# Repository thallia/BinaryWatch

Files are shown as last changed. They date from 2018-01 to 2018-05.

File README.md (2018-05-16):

# BinaryWatch
My first project designing and creating *everything*. 

Current board rev: *4.1*

Supplies I went through for breadboard testing:
  * atmega328p-pu
  * sn74hc595n x2
  * LEDs x10 
  * 16MHz external crystal
  * 32.768kHz external crystal
  * 2 22pF capacitors
  * 2 0.1uF capacitors
  * two buttons for configuring time
  * one button for sleep/wakeup
  * jumper wires
  
  * arduino uno (for easier programming in the beginning)
  
Supplies for PCB:
  * (SMD) atmega328p-au 
  * 74hc595 SMD shift registers x2
  * JST right angle connector
  * 400mAh Li-Po battery
  * LEDs 1206 SMD x10 (or flat top, whatever you prefer.)
  * 32.768kHz SC-32S SMD crystal
  * SMD capacitors 0805 22pF x2
  * SMD capacitors 0805 12.5pF x2
  * 3 buttons
  * 10k SMD resistors 0805 x1
  * 2k SMD resistors 0805 x10 (in testing for LED brightness)
  * PCB (oshpark)
  * 3D printed case (fusion360)

**PCB designed on:** eagleCAD

**3D case designed on:** fusion360

**CURRENT TASK:** This project is complete!

Blog Posts following development:

**Basis:**  https://thalliatree.wordpress.com/2017/12/25/74hc595-texas-instruments-shift-registers/

**Intro:**  https://thalliatree.wordpress.com/2018/01/01/project-hype-binary-wristwatch/

**Breadboard Hardware (with Uno):**   https://thalliatree.wordpress.com/2018/01/26/atmega328p-microcontroller-74hc595-shift-register-setup-and-test-binary-watch/

**Code - Part 1:**  https://thalliatree.wordpress.com/2018/01/29/code-part-1-binary-watch/

**Code - Part 2:**  https://thalliatree.wordpress.com/2018/01/31/code-part-2-binary-watch/

**Breadboard Hardware (without Uno):**    https://www.thalliatree.net/posts/prepping-the-atmega-hardware-test-bw.html

**Mock Up PCB with coin cells + early schematic:**   https://thalliatree.wordpress.com/2018/02/05/mock-up-pcb-binary-watch/

**Code - Part 3:**   https://thalliatree.wordpress.com/2018/03/16/code-part-3-binary-watch/

**Atmega328p 32.768kHz, sleep modes, and new schematic:**   https://thalliatree.wordpress.com/2018/03/26/atmega328p-32-768khz-sleep-modes-and-new-schematic-binary-watch/

**Final Code, Schematic, and PCB layout:**   https://thalliatree.wordpress.com/2018/04/03/final-code-schematic-and-pcb-binary-watch/

**PCB 95% Complete:**   https://thalliatree.wordpress.com/2018/05/03/pcb-95-complete-binary-watch/

**Binary Watch | Complete:**  https://thalliatree.wordpress.com/2018/05/14/binary-watch-complete

For later revisions: 
-  Power: The charging and power circuit needs to be on the board itself. That way I can charge it and not have to worry about buying a bunch of LiPo batteries over and over.
- Experimenting with new power: I want to try powering this thing from a coin cell again. I have 2 other boards with this design, so I'm going to solder them together, but with different resistor types on the LEDs to see how much current the LEDs and microcontroller are drawing. That way I can estimate what the best resistor value is for brightness + mAh value of battery to get.
- The 3D case is cool with the PCB exposed, but it ain't cool because it's exposed to the weather and other wet and sticky things. Therefore I must cover it up. The lid for case I design next will likely be screwed on, 1) for easier access and 2) for better security of the PCB. Depending on how secure I want it, I may add some kind of sealant. We'll see...
- 3D case: If I add a charging port, it'll need a hole for the plug.
- Through-hole LEDs: if the PCB is to be covered by the case, SMD LEDs aren't going to shine through very well. I have some cool cylindrical blue LEDs that should work, so I'll have to design the case cover to sit around/on top of them, which requires a new PCB design entirely.
- With the PCB case covering the top, I'll need to either add holes for the pushbuttons or design a way to put them on the sides of the case.
- Watch strap: I'm planning on weaving some leather cord in a celtic knot fashion, or maybe some cool braided thing. I've been looking at some chunkier weaves on Pinterest, but I haven't found the right one yet.
- With the new case top, I may make it thicker and engrave some cool circuit-looking designs around the LEDs poking through and paint the engravings an electric blue color. Electric blue is a great idea.

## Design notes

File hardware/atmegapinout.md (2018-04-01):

# ATMega328P Pinout
## Connecting what pins from the ATMega to the shift registers?

ATMEGA **to** 74HC595

Digital Pin 0 (PCINT16/RXD) PD0 **to** OE (output enable) pin 13

Digital Pin 1 (PCINT17/TXD) PD1 **to** ST_CP (clock pin) pin 12

Digital Pin 2 ((PCINT18/INT0) PD2) **to** inDisplay

Digital Pin 3 (PCINT19/OC2B/INT1) PD3 **to** 

Digital Pin 4 (PCINT20/XCK/T0) PD4 **to** SH_CP (latch pin) pin 11

Digital Pin 5 (PCINT21/OC0B/T1) PD5 **to** DS (serial data) pin 14

Digital Pin 6 ((PCINT22/OC0A/AIN0) PD6) **to** inHour

Digital Pin 7 ((PCINT23/AIN1) PD7) **to** inMinute

# Shift Register I/O to LED

### Hours

- Pin Q1 = 1
- Pin Q2 = 2
- Pin Q3 = 4
- Pin Q4 = 8

### Minutes

- Pin Q5 = 1
- Pin Q6 = 2
- Pin Q7 = 4
- (second shift register)
- Pin Q0 = 8
- Pin Q1 = 16
- Pin Q2 = 32

# GND and Vcc

- AREF to Vcc
- AVcc to Vcc
- GND to GND
- Vcc to 10kOhm resistor to RESET
- Master Reclear to Vcc
- Two 0.1uF capacitors connecting GND and Vcc on both sides (Vcc/GND and AVcc/GND)

# External Clock

- Two GNDed 22pF capacitors to 16MHz crystal to XTAL1 and XTAL2 (if not using sleep modes)

OR

- Two GNDed 22pF caps to 32.768kHz crystal to XTAL1 and XTAL2 (if using sleep modes & burned fuse bytes)

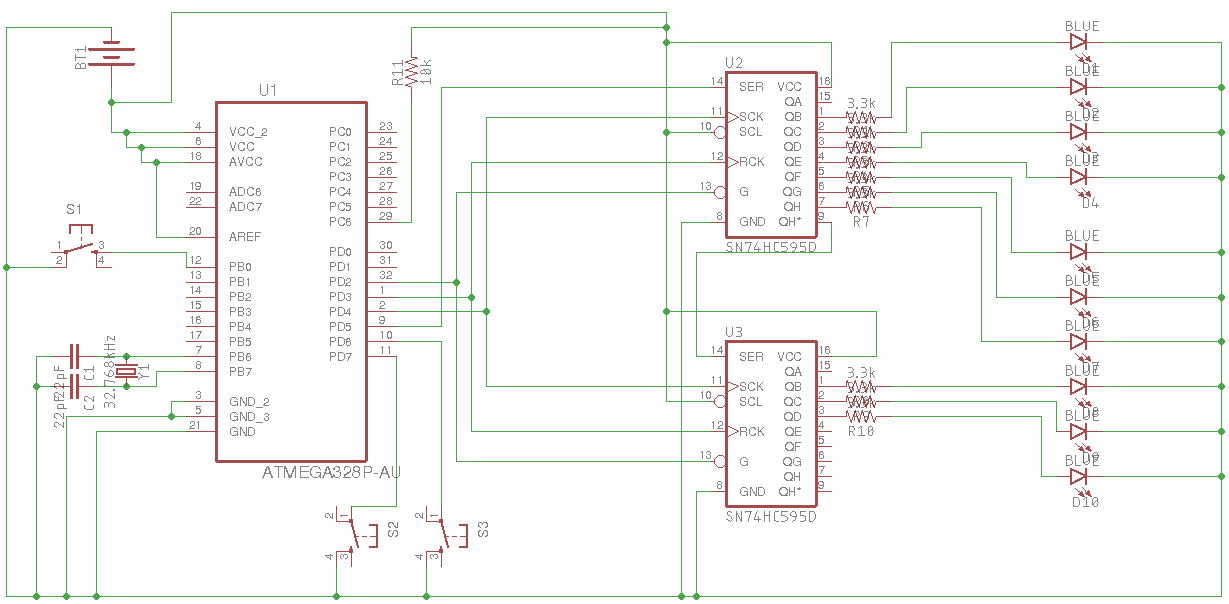
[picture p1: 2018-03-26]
hardware/schematics/binarywatchrev4.png

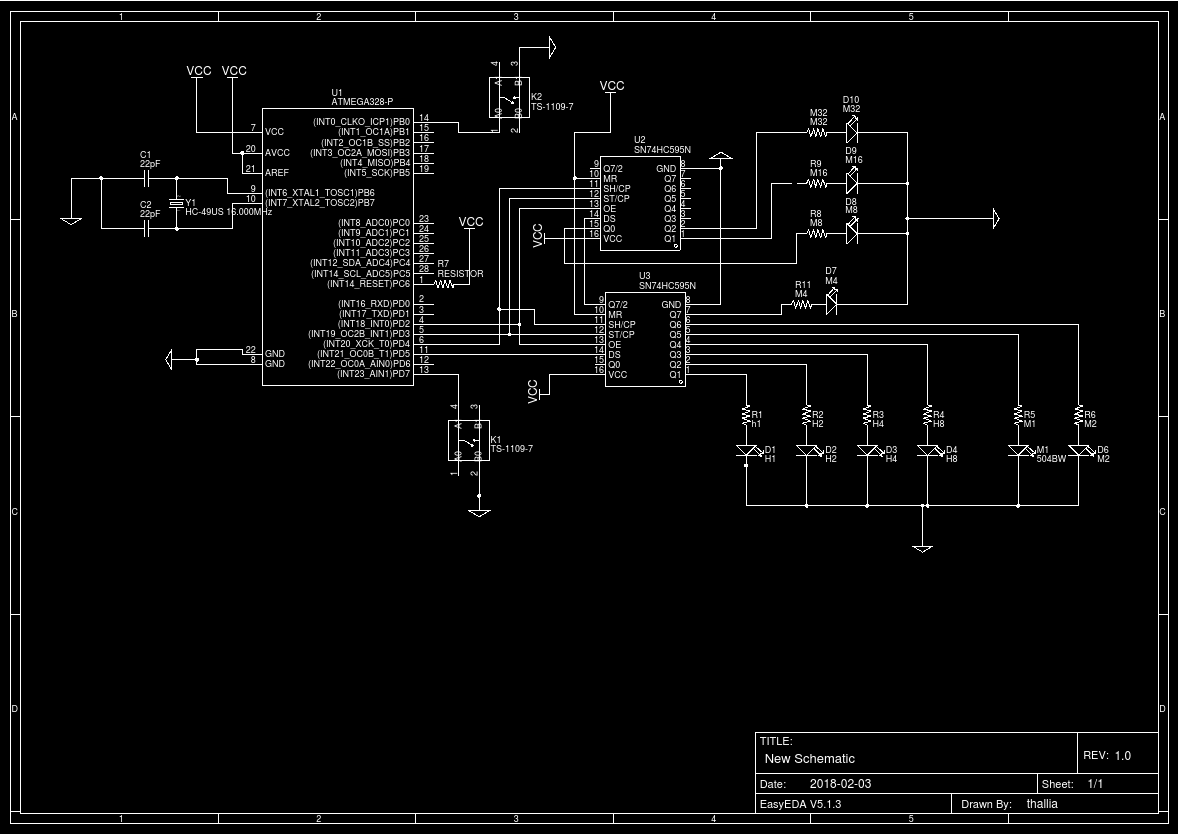
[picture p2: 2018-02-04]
hardware/schematics/schematicrv1.png

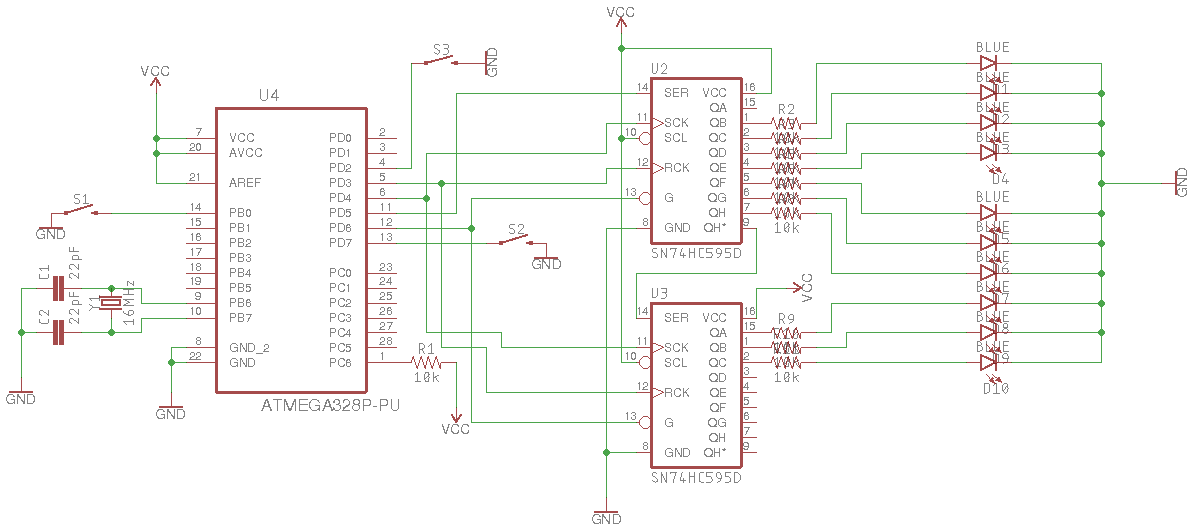
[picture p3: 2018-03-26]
hardware/schematics/binarywatchrev3-1.png

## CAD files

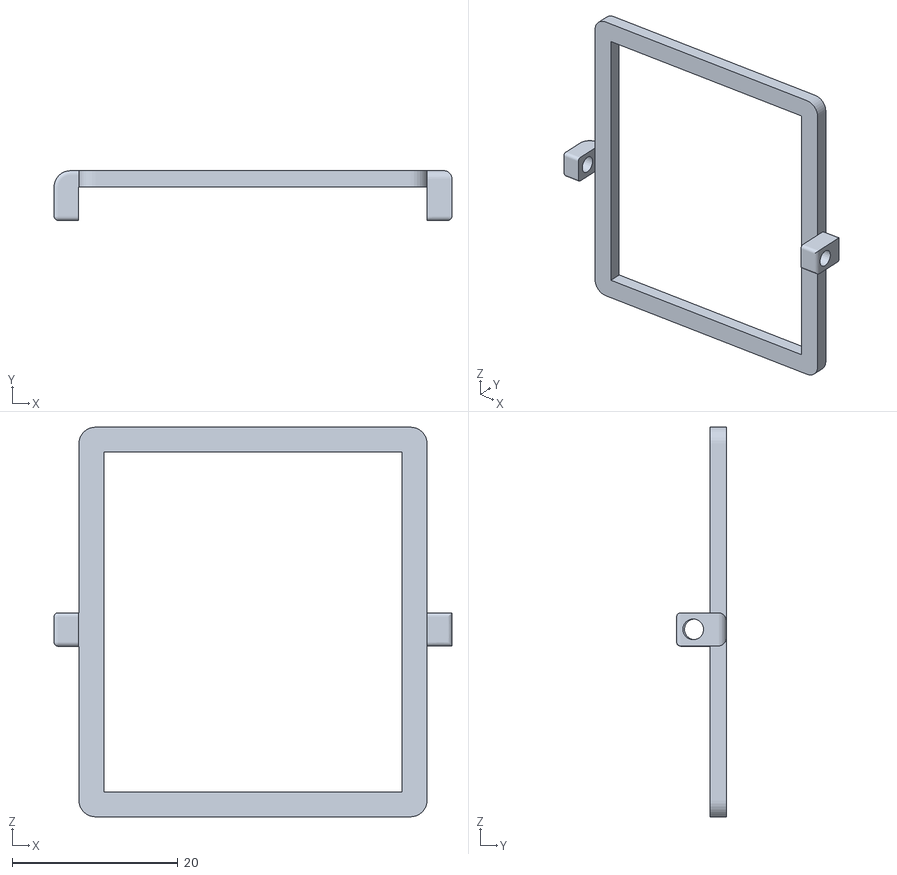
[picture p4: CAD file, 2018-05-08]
hardware/3d-case-rev-2/lid.stl
48.0 x 6.00 x 47.0

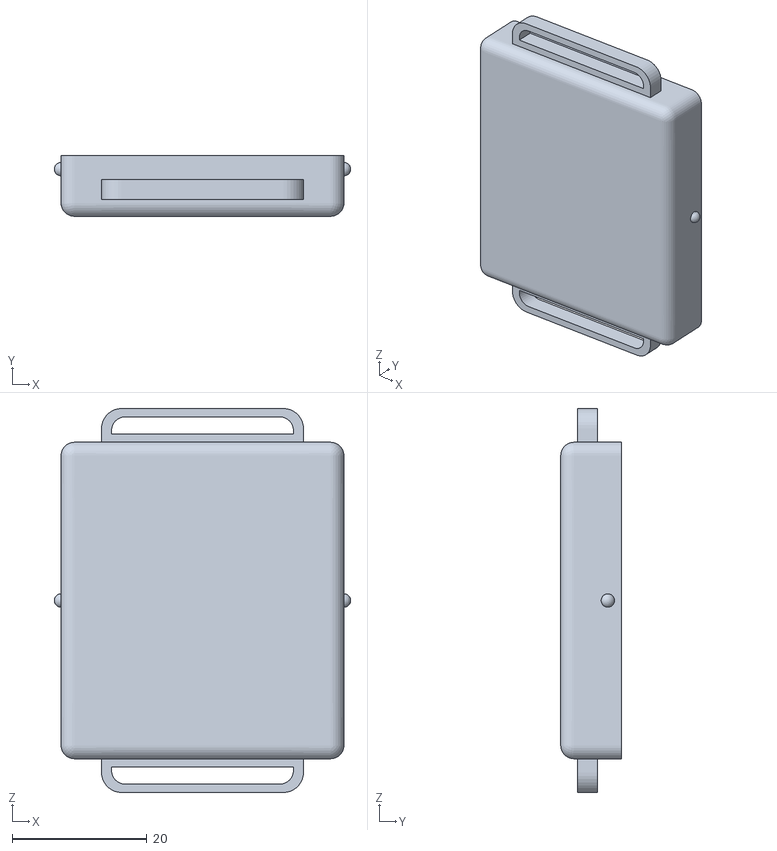
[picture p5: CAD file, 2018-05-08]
hardware/3d-case-rev-2/case.stl
44.0 x 9.00 x 57.0

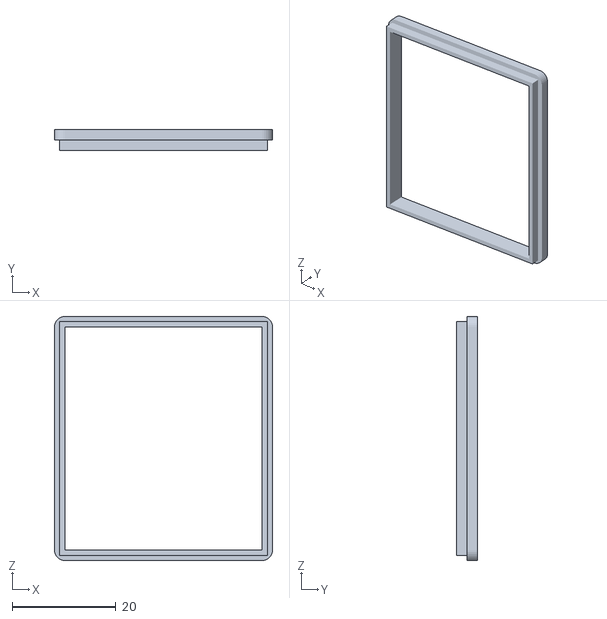
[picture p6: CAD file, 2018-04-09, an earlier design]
hardware/3d-case-rev-1/lid.stl
42.0 x 4.00 x 47.0

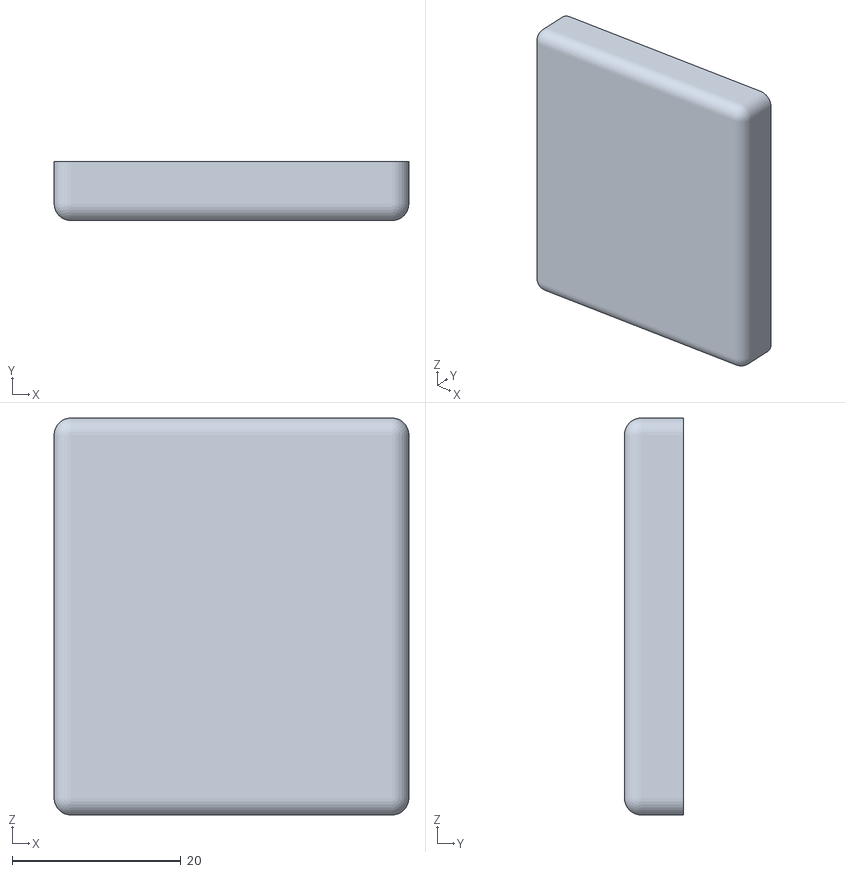
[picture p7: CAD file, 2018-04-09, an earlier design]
hardware/3d-case-rev-1/base.stl
42.0 x 7.00 x 47.0

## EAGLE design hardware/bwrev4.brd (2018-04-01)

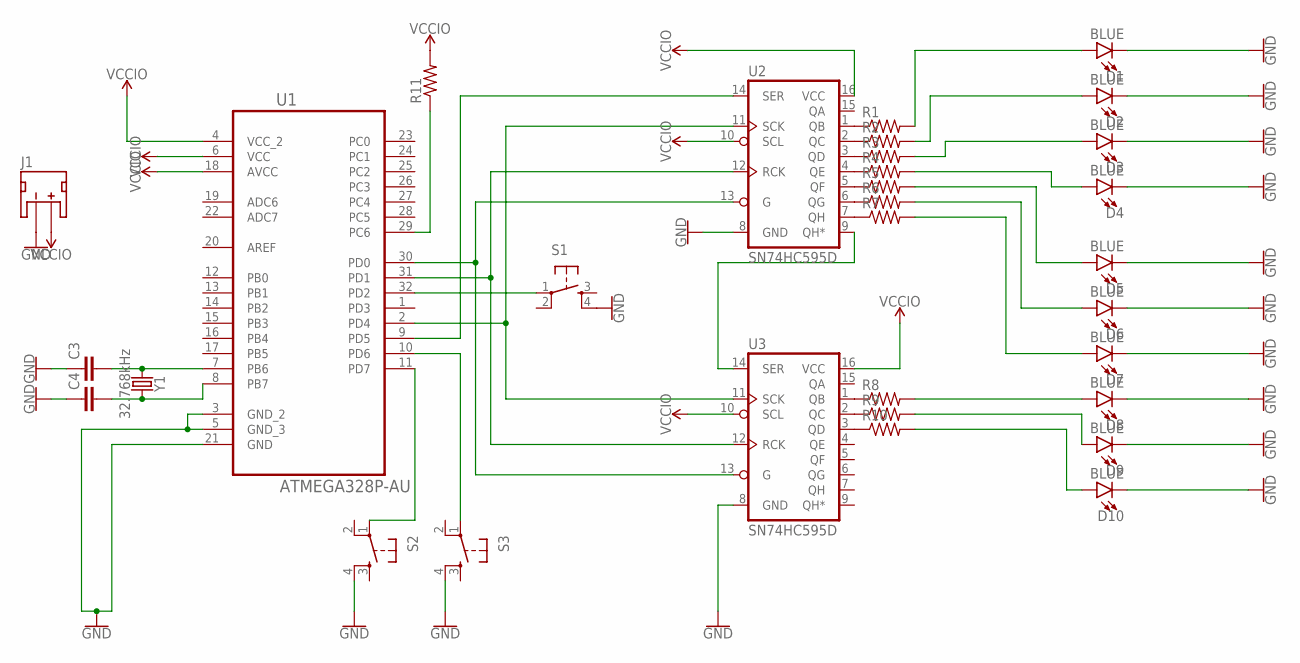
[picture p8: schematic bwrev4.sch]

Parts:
C3, C4: C-EUC0805; C0805
D1, D2, D3, D4, D5, D6, D7, D8, D9, D10: BLUE; LED-1206
J1: JST_2MM_MALE; JST-2-SMD
R1, R2, R3, R4, R5, R6, R7, R8, R9, R10, R11: R-US_M0805; M0805
S1, S2, S3: TAC_SWITCHPTH; TACTILE-PTH
U1: ATMEGA328P-AU; QFP80P900X900X120-32N
U2, U3: SN74HC595D; SO16
Y1: 32.768kHz; CRYSTAL-SMD-3.2X1.5MM

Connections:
GND: C3.1, C4.1, D1.C, D2.C, D3.C, D4.C, D5.C, D6.C, D7.C, D8.C, D9.C, D10.C, J1.1 (-), S1.4, S2.4, S3.4, U1.3 (GND_2), U1.5 (GND_3), U1.21 (GND), U2.8 (GND), U3.8 (GND)
unnamed: S1.1, U1.32 (PD2)
unnamed: R1.1, U2.1 (QB)
unnamed: R2.1, U2.2 (QC)
unnamed: R3.1, U2.3 (QD)
unnamed: R4.1, U2.4 (QE)
unnamed: R5.1, U2.5 (QF)
unnamed: R6.1, U2.6 (QG)
unnamed: R7.1, U2.7 (QH)
unnamed: R8.1, U3.1 (QB)
unnamed: R9.1, U3.2 (QC)
unnamed: S3.1, U1.10 (PD6)
unnamed: C4.2, U1.8 (PB7), Y1.P$2 (2)
unnamed: C3.2, U1.7 (PB6), Y1.P$1 (1)
unnamed: R10.1, U3.3 (QD)
unnamed: D4.A, R4.2
unnamed: D5.A, R5.2
unnamed: D1.A, R1.2
unnamed: D2.A, R2.2
unnamed: D3.A, R3.2
unnamed: D6.A, R6.2
unnamed: D7.A, R7.2
unnamed: D8.A, R8.2
unnamed: D9.A, R9.2
unnamed: D10.A, R10.2
unnamed: U2.9 (QH*), U3.14 (SER)
unnamed: U1.30 (PD0), U2.13 (G), U3.13 (G)
unnamed: U1.9 (PD5), U2.14 (SER)
unnamed: U1.31 (PD1), U2.12 (RCK), U3.12 (RCK)
unnamed: U1.2 (PD4), U2.11 (SCK), U3.11 (SCK)
unnamed: R11.1, U1.29 (PC6)
unnamed: S2.1, U1.11 (PD7)
VCCIO: J1.2 (+), R11.2, U1.4 (VCC_2), U1.6 (VCC), U1.18 (AVCC), U2.10 (SCL), U2.16 (VCC), U3.10 (SCL), U3.16 (VCC)

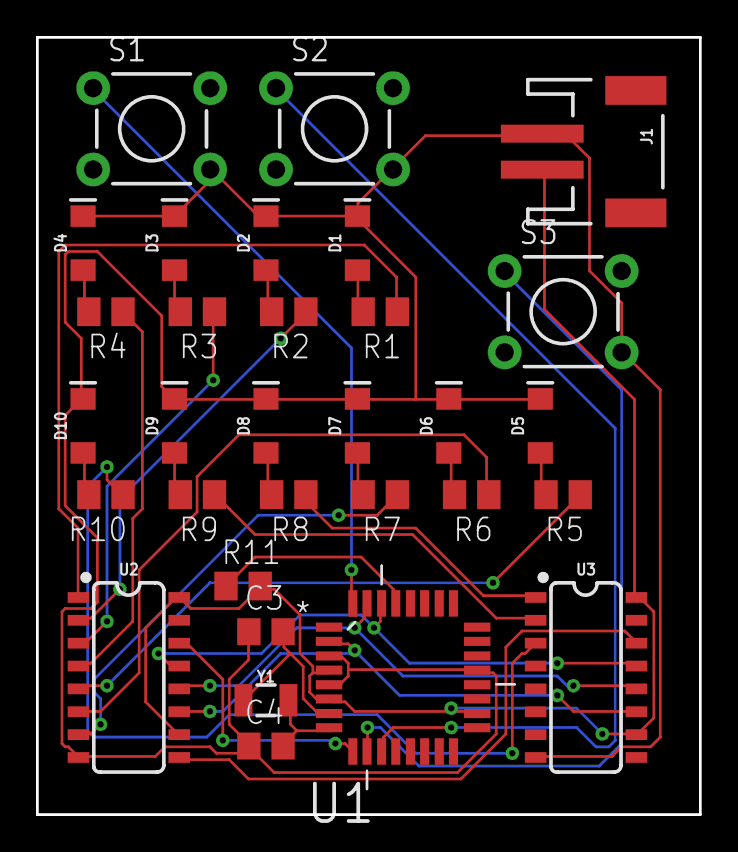
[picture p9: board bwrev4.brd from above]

Board: 2 copper layers, 36.8 x 43.2 mm, 31 parts (0 on the bottom side), 33 nets.

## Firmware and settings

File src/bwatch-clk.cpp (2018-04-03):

/*
*
* written by: thallia
* date: 3-14-18
* last edit: 3-31-18
* Specifically only using the 32kHz clock, adjusting the hardware to fit it.
*
*/
#include <avr/sleep.h>
#include <avr/power.h>

const int inDisplay = 2;  // display button
const int inHour = 6;     // hour button
const int inMinute = 7;   // minute button

const int outputEN = 0;   // enable chip signal
const int clockP = 1;     // clock signal pin
const int latchP = 4;     // latch signal pin
const int dataP = 5;      // data write pin

// Default date/time settings whenever program starts
int seconD = 0;
int minutE = 0;
int houR = 1;
int halfDay = 1;

int checkDisplay = 0;

// interrupt on Timer 2 compare "A" completion - does nothing
EMPTY_INTERRUPT (TIMER2_COMPA_vect);

// Boolean --> Void / pin signal
// If true, enableOutput writes an ON signal to the OE gate, allowing LED output
// if false, enableOutput writes OFF signal to the OE gate.
void enableOutput(boolean state){
  if(state){
    digitalWrite(outputEN, LOW); // OE is NOTed, which is why we write LOW to
                                 // trigger a HIGH signal.
  } else{
    digitalWrite(outputEN, HIGH);
  }
}

void latchTick(){
  digitalWrite(latchP, HIGH);
  digitalWrite(latchP, LOW);
  digitalWrite(clockP, HIGH); // turns the clock on
  digitalWrite(clockP, LOW); // turns clock off
}

// Integer --> Void / Pin Signal
// writeData writes the new data to the dataPin.
void writeData(){
  digitalWrite(dataP, HIGH);
  latchTick();
  digitalWrite(dataP, LOW);
}

// No input --> No output
// checkHour checks if the hourButton has been pressed. If true, increase
// the LED output.
void checkHour(){
  int hourButton = digitalRead(inHour);
  if(hourButton == LOW){
    houR++;
    seconD = 0;
  }
}

// no input --> no output
// check minute checks if the minButton has been pressed. If true, increase
// the min LED output.
void checkMin(){
  int minButton = digitalRead(inMinute);
  if(minButton == LOW){
    minutE++;
    seconD = 0;
  }
}

// Integer --> LED signal (hours)
// writes to the hour display
void hourDisplay(int houR){
  if(houR >= 1){
    for (int x = 3; x >= 0; x--){
      int bit = bitRead(houR, x);
        if(bit == 1){
          writeData();
        } else {
          latchTick();
       }
    }
  }
}

// integer --> LED signal (minutes)
// writes to the minute display
void minDisplay(int minutE){
  for(int x = 5; x >= 0; x--){
    int bit = bitRead(minutE, x);
    if(bit == 1){
      writeData();
    } else {
      latchTick();
    }
  }
}

// integer --> void
// AmPm makes sure that we see regular time, not military time.
void ampm(int state){
  if(state >= 1){
    writeData();
  } else {
    latchTick();
  }
}

/* ------------------------------------------------------------------------- */

void setup()
 {

   pinMode(clockP, OUTPUT);
   pinMode(outputEN, OUTPUT);
   pinMode(latchP, OUTPUT);
   pinMode(dataP, OUTPUT);

   pinMode(inHour, INPUT_PULLUP);
   pinMode(inMinute, INPUT_PULLUP);
   pinMode(inDisplay, INPUT_PULLUP);

  // clock input to timer 2 from XTAL1/XTAL2
  ASSR = bit (AS2);

  // set up timer 2 to count up to 32 * 1024  (32768)
  // timer counts to 32*1024 which takes 1 sec, then triggers interrupt
  TCCR2A = bit (WGM21);                             // CTC
  TCCR2B = bit (CS20) | bit (CS21) | bit (CS22);    // Prescaler of 1024
  OCR2A =  31;              // count to 32 (zero-relative)

  // enable timer interrupts
  TIMSK2 |= bit (OCIE2A);

  // disable ADC
  ADCSRA = 0;

  // turn off everything we can
  power_adc_disable();
  power_spi_disable();
  power_twi_disable();
  power_timer0_disable();
  power_timer1_disable();
  power_usart0_disable();

  // full power-down doesn't respond to Timer 2
  set_sleep_mode(SLEEP_MODE_PWR_SAVE);

  // get ready ...
  sleep_enable();

  }  // end of setup

void loop()
  {
  enableOutput(false);

  // turn off brown-out enable in software
  MCUCR = bit(BODS) | bit(BODSE);
  MCUCR = bit(BODS);

  // sleep, finally!
  sleep_cpu();

  // we awoke! pulse the clock hand
  // digitalWrite(tick, ! digitalRead(tick));
  seconD++;
  // one minute every 60sec
  if(seconD >= 59){
    minutE++;
    seconD = 0;
  }

  // one hour every 60min
  if(minutE >= 59){
    houR++;
    minutE = 0;
  }

  // halfDay every 12hrs
  if(houR >= 13){
    halfDay++;
    houR = 1;
    minutE = 1;
  }

  // reset AM/PM
  if(halfDay >= 2){
    halfDay = 0;
    houR = 1;
    minutE = 0;
  }

  checkHour();
  checkMin();

  checkDisplay = digitalRead(inDisplay);
  if (checkDisplay == LOW){
    ampm(halfDay);
    minDisplay(minutE);
    hourDisplay(houR);
    latchTick();
    enableOutput(true);
  }
}  // end of loop: loop back, sleep, wake up after 1 second

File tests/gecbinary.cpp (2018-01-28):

/*
 * AUTHOR: Gector (with lovely comments from thallia)
 * Written: 12/21/2017
 * Last Edit: 1-27-18 - thallia's descriptive comment
 */

// -------------------------------------- \\
// ------------ VARIABLES --------------- \\
// -------------------------------------- \\

// Our time units.
int second=0, minute1=1, minute2=1, hour=1, halfDay=1;

// Physical pin numbers. 
const int inHourPin = 12, inMinutePin = 13;
const int outEnable = 2;
const int clockPin = 3;
const int dataPin = 5;
const int latchPin = 4;

const int clearAmount = 16; // If you add more shift registers to clear.

int wait = 0; // Add delay to the clock to see it shift stuff


// -------------------------------------- \\
// ------------ FUNCTIONS --------------- \\
// -------------------------------------- \\

// Shift bits down by one (positive edge triggered)

///////// THALLIA COMMENT //////////
/* clockReg takes looks like it makes a new variable "hold", then places the int value of 'wait' inside of it.
with digitalWrite, it outputs the clockpin HIGH, sending a signal to the clock pin of the shift register.
the delay....does something.

Delay waits for whatever the value of "hold" is.
digitalWrite then writes the clockpin LOW, and waits 1 second. This seems to be used as a way to clock the shift registers. */
///////////////////////////////////////////////////////
void clockReg(int hold = wait){
  digitalWrite(clockPin, HIGH);
  delay(hold);
  digitalWrite(clockPin, LOW);
  delay(hold);
}

// Grab a new bit from input (positive edge triggered)

////////// THALLIA COMMENT //////////
/* I'm guessing latch does the same thing as clockReg, but on the latch pin to get the new value. we don't have to specify *how* to get the value, only tell the pin to latch it. We like smart pins. */
/////////////////////////////////////////////////
void latch(int hold = wait){
  digitalWrite(latchPin, HIGH);
  delay(hold);
  digitalWrite(latchPin, LOW);
  delay(hold);
}

// Activate a single bit

//////////// THALLIA COMMENT ///////////////
/* alright, this is a little different.
 activateBit takes....an integer variable named hold with the value of wait inside of it?

digitalWrite writes the dataPin, which activates the LED, I think.
latch(hold) takes hold as an argument and latches the data.

activateBit grabs writes the old data, grabs the new data, and then writes the pin low, we aren't ready to latch the new stuff yet. */
///////////////////////////////////////////////////
void activateBit(int hold = wait){
  digitalWrite(dataPin, HIGH);
  latch(hold);
  clockReg(hold);
  digitalWrite(dataPin, LOW);
}

// set whether or not the LEDs are lit or not. (if this isn't done they flicker with the calculations)

///////// THALLIA COMMENT ///////////
/* enableOutput takes a boolean state as an argument.
 if the boolean state is true,if OE will be written LOW. But because that pin is inverted input, it'll be high. Otherwise, if false, OE will be written high, and turned off. */
////////////////////////////////////////////////////
void enableOutput(boolean state){
  if(state) {
    digitalWrite(outEnable, LOW);
  } else {
    digitalWrite(outEnable, HIGH);
  }
}

//... clear all.
//////// THALLIA COMMENT ////////////////
/* clearAll doesn't take any arguments afaik.
 It writes the dataPin low/off and loops:

*if x is 0, x less than the value of clearAmount, x++? then execute clockReg and latch with values 0.

clockReg will take 0 as an arg, running the clock and latching the new data. This resets everything to new values, I guess? */
/////////////////////////////////////////////////
void clearAll(){
  digitalWrite(dataPin, LOW);
  for(int x = 0;x <= clearAmount; x++){
    clockReg(0);
    latch(0);
  }
}

// Display hours
//////////////////THALLIA COMMENT/////////////////////
/* displayHour is obvs for displaying the actual time on the LEDs.

 if hour is greater than or equal to 1:
         for x equal to 3, greater than zero, read in the value from bitRead, which reads the number from "hour" and the bit in the x's place.

if the local variable "bit" is equal to 1, then write data HIGH, latch a new value, and shift it down, then turn data off.
otherwise, keep ticking. */
//////////////////////////////////////////////////////
void displayHour(int hour){
  if(hour >= 1) {
    for(int x = 3; x >= 0; x--) {
      int bit = bitRead(hour, x);
      if(bit == 1){ // Clock and data
        digitalWrite(dataPin, HIGH);
        latch();
        clockReg();
        digitalWrite(dataPin, LOW);
      } else { // Just clock
        latch();
        clockReg();
      }
    }
  }
}

// Sends on extra bit if it's PM, sends one extra clock if it's AM

////////////// THALLIA COMMENT ////////////////
/* AmPm returns nothing. It takes a state with an integer datatype. If state is greater than one, write data, latch new data, shift the clock. Otherwise, keep ticking. */
///////////////////////////////////////////////
void AmPm(int state){
  if(state >= 1) {
    digitalWrite(dataPin, HIGH);
    latch();
    clockReg();
    digitalWrite(dataPin, LOW);
  } else {
    latch();
    clockReg();
  }
}

// Set the first line of LEDs designated to minutes

///////////// THALLIA COMMENT ////////////////
/* this sets the first set of LEDs as the tens row.

 if the bit read from the local variable 'tens' is equal to 1, write, latch, and clock

otherwise, keep ticking */
//////////////////////////////////////////////
void displayMinL1(int tens){
  for(int x = 3; x >= 0; x--) {
    int bit = bitRead(tens, x);
    if(bit == 1){ // Clock and data
      digitalWrite(dataPin, HIGH);
      latch();
      clockReg();
      digitalWrite(dataPin, LOW);
    } else { // Just clock
      latch();
      clockReg();
    }
  }
}

// Set the second line of LEDs designated to minutes
void displayMinL2(int ones){
    for(int x = 3; x >= 0; x--) {
      int bit = bitRead(ones, x);
      if(bit == 1){ // Clock and data
        digitalWrite(dataPin, HIGH);
        latch();
        clockReg();
        digitalWrite(dataPin, LOW);
      } else { // Just clock
        latch();
        clockReg();
      }
    }
}

// Set all bits in sequence - usefuly for both lookinng cool and for debugging.

/////////////THALLIA COMMENT /////////////////
/* view takes an integer or hold as arg.
 if the given arg is equal to 0, less than clearAmount, it'll activate a bit -- I think whatever hold is, which is the pin number?? */
//////////////////////////////////////////////
void view(int hold = wait){
  for(int x = 0;x <= clearAmount; x++){
    activateBit(hold);
  }
}

// -------------------------------------- \\
// -------------- MAIN ------------------ \\
// -------------------------------------- \\
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

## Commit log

2018-01-03 added eagleCAD gerber and board files for rev2.1
    [bwv2.1.brd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]
2018-01-28 added initial binary watch rev 1 code
    It's in good standing, it works, albeit slightly better than how Gector's reacted on my atmega. I altered the minute function, but it's
    still acting up, so that will be the next thing to fix.
    [bwv2.1.brd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]
2018-01-29 fixed the minute portion of the code
    replaced the if(millis() - lastTick) with the correct stuff, turns out that had been goofing the whole thing up. Now onto deep sleep.
2018-01-30 solved why minutes won't go to 59 had to add else's to the IF functions for the buttons. Now to find out why they aren't receiving input, and why having both checkHour and checkMin causes some sort o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
2018-01-31 modified the inHour and inMinute to be input and activated the pullup resistors
2018-01-31 fixed the pullup resistor code, it works with the arduino uno!
2018-01-31 updated README to most recent additions, current task, and list of blog post documentation of process
2018-01-31 added the correct pinout of ATMega --> shift register, and shift register I/O to LED number
2018-02-04 added rest of pins to connect to to make circuit work
2018-02-04 added rest of pins to connect to to make circuit work - oops forgot caps
2018-02-04 schematic from EasyEDA for scholarship; going to redo in eagleCAD. Document.
2018-03-13 cleaned up the bclock and replaced with bwatch. Bwatch is where i'm gonna test all the disabled modules.
    [bwatch2-0.cpp]
2018-03-16 updated task, PCB supplies, cleaned up code.
2018-03-25 figured out the sleep modes and fuse bytes!
2018-03-26 working code w/ 32.786kHz clock! buttons untested.
2018-03-26 working code(32kHz) minus the buttons.
2018-03-26 eagle cad schematic rev3-1
2018-03-26 ugly final schematic
2018-03-30 testing files for new hardware + pin changes.
2018-04-01 fixed time changing buttons in code, added updated hardware pins.
    [bwatch-clk.cpp]
2018-04-01 final schematic and PCB layout.
    [bwrev4.brd, bwrev4.sch]
2018-04-09 fusion360 STL files.
    [base.stl, lid.stl]
2018-05-08 Revised the 3D case to more efficient for using
    [base.stl, case.stl, lid.stl]
2018-05-08 updated lid to be slightly more covering.
    [lid.stl]

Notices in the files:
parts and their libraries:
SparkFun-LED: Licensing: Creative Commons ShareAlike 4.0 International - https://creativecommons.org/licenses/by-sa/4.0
